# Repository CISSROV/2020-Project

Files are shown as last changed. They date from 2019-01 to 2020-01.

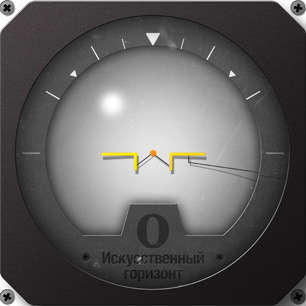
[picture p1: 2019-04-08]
code/web/artificial_horizon/images/tool_320_2.png

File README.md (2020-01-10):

# 2020-Project
CISS ROV-MATE 2020 <br>

### Link to Raspi SD card images
(<a href="https://www.dropbox.com/s/ywiuz3bnbsoy6am/MATE_Topside_2019.img?dl=0">topside</a>, <a href="https://www.dropbox.com/s/pmv8e9o7058bai0/MATE_Camera_2019.img?dl=0">camera</a>, <a href="https://www.dropbox.com/s/j6l58o7ey1v0xhj/MATE_Motor_2019.img?dl=0">motor</a>) (outdated)

### 2019 Presentation link

Documentation: https://drive.google.com/drive/folders/1_E8WjAePvzNWnD8-W-GRQ3ELVlIdNNk-?usp=sharing

### Coding Problems & Code Documentation

Documentation: https://cissrov.github.io/2020-Project/code/

For questions about the code used in 2019 and moved to this repository,  
contact Jonathan Rotter (hydrogen602) at jonathan.p.rotter@gmail.com

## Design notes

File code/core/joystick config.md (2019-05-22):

# NOTES - pygame events and values

### JOYAXISMOTION
event.axis              event.value  
0 - x axis left thumb   (+1 is right, -1 is left)
1 - y axis left thumb   (+1 is down, -1 is up)
2 - left trigger
3 - x axis right thumb  (+1 is right, -1 is left)
4 - y axis right thumb  (+1 is down, -1 is up)
5 - right trigger

### JOYBUTTONDOWN | JOYBUTTONUP
event.button  

A = 0
B = 1
X = 2
Y = 3
LB = 4
RB = 5

BACK = 6
START = 7
XBOX = 8
LEFTTHUMB = 9
RIGHTTHUMB = 10

### idk

[0] - horizontal
[1] - vertival
[0].0 - middle
[0].-1 - left
[0].+1 - right
[1].0 - middle
[1].-1 - bottom
[1].+1 - top

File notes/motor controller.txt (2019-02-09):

Notes for the small motor controllers

Basic code to make them run:

int IN1 = 9; // <- labeled on the controller
int IN2 = 10; // <- labeled on the controller

void setup() {
  pinMode(IN1, OUTPUT);
  pinMode(IN2, OUTPUT);

  digitalWrite(IN1, HIGH); // <- controls the direction of rotation
}

void loop() {
  analogWrite(IN2, 205);
  /* 
   * 2nd argument should be between 0-255
   * It controls speed
   * If IN1 is HIGH, then 255 is stop and 0 is max speed
   * If IN1 is LOW, then 0 is stop and 255 is max speed
   * 
   */
}

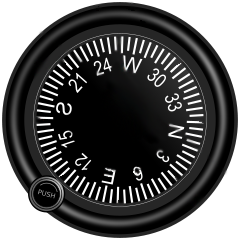
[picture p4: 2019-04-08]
code/web/heading/noplane.png

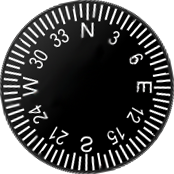
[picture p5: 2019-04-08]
code/web/heading/noplane_center.png

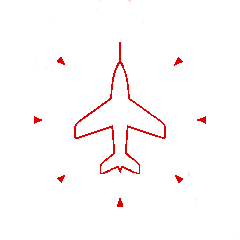
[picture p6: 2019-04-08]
code/web/heading/plane3.png

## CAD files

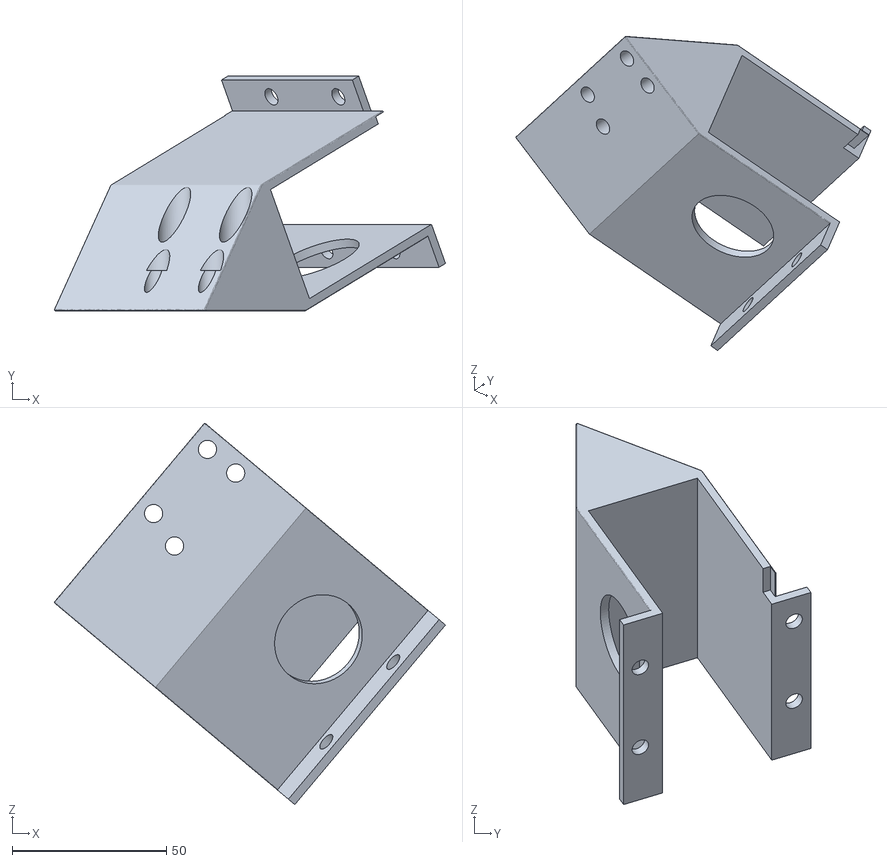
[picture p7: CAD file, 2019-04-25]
STLs/Camera Mount Top downview v2.stl
126.8 x 76.1 x 123.6

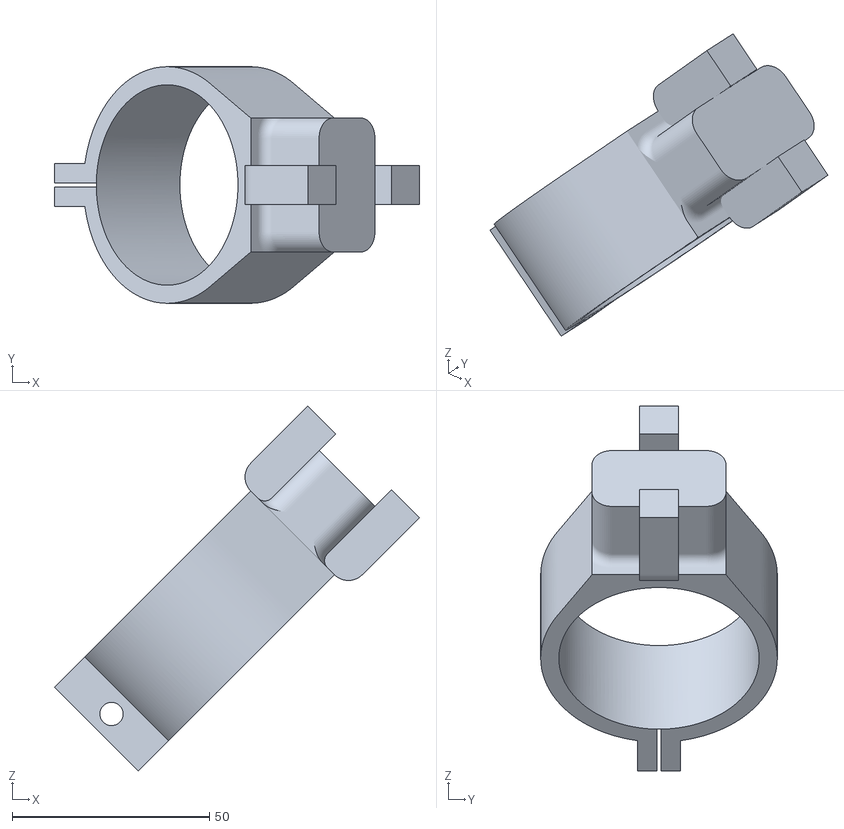
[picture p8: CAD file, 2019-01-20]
STLs/EngineMountClamp/EngineMountClampV0.1.stl
92.6 x 60.0 x 92.6

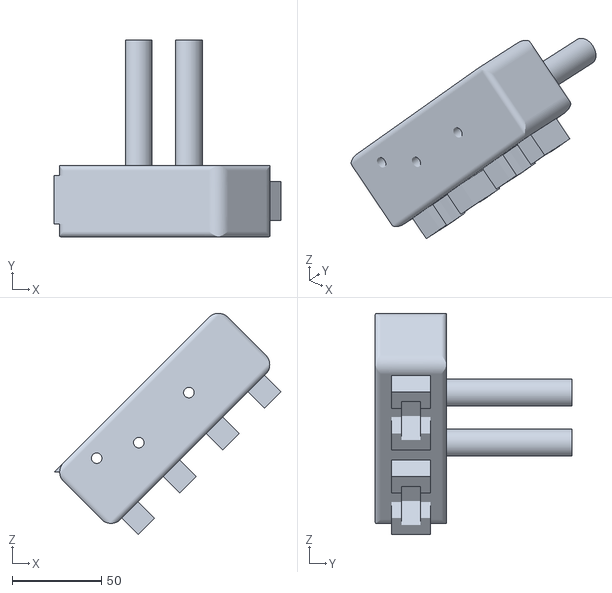
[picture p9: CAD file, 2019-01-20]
STLs/EngineMountHolder/EngineMountHolderV0.1.stl
127.0 x 110.0 x 123.8

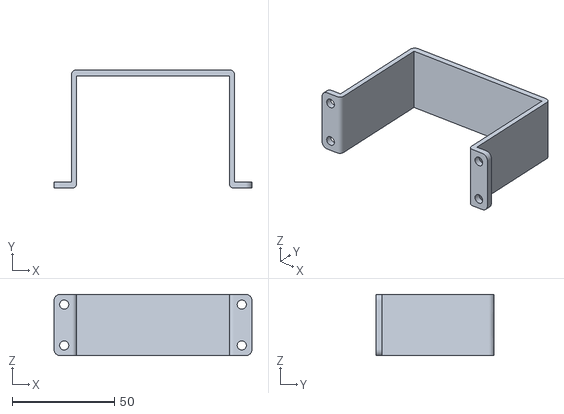
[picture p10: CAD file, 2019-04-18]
STLs/cameramounttop.stl
97.0 x 58.0 x 30.0

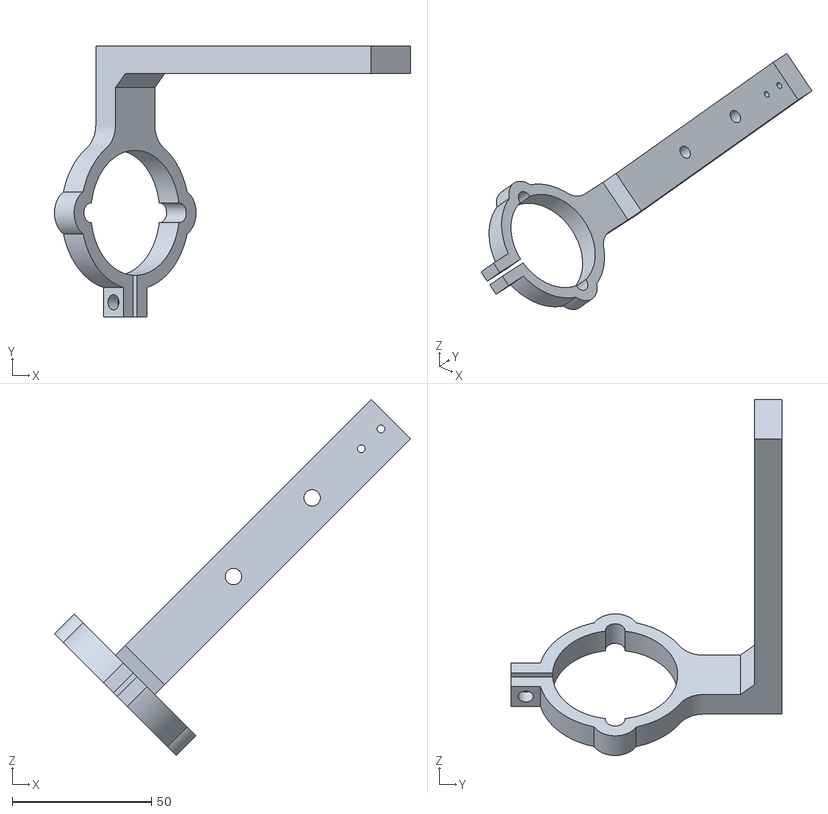
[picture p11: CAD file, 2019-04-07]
STLs/Clamp Base + Mount V2.stl
128.0 x 97.5 x 128.0

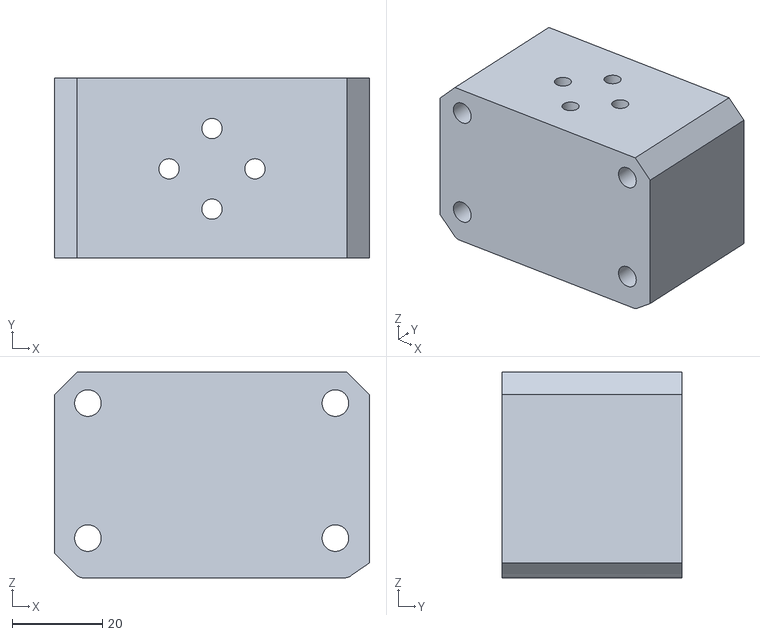
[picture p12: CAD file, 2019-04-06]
STLs/Vert Thruster V3.stl
70.0 x 40.0 x 45.7

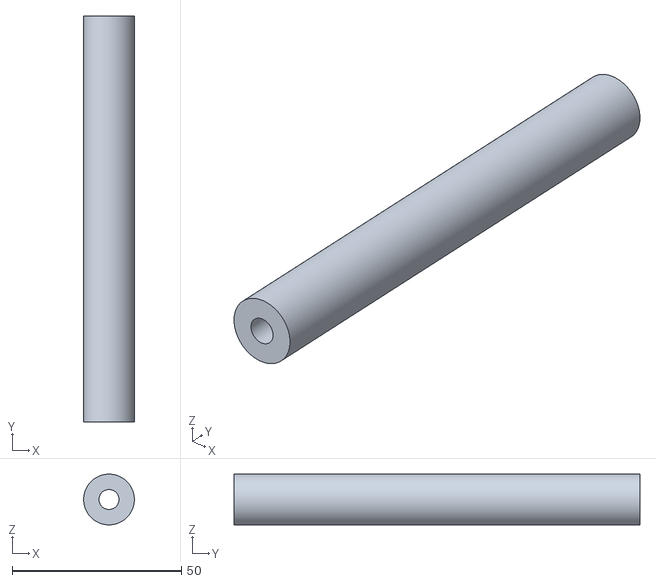
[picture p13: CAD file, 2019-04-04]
STLs/Standoff.stl
15.0 x 120.0 x 15.0

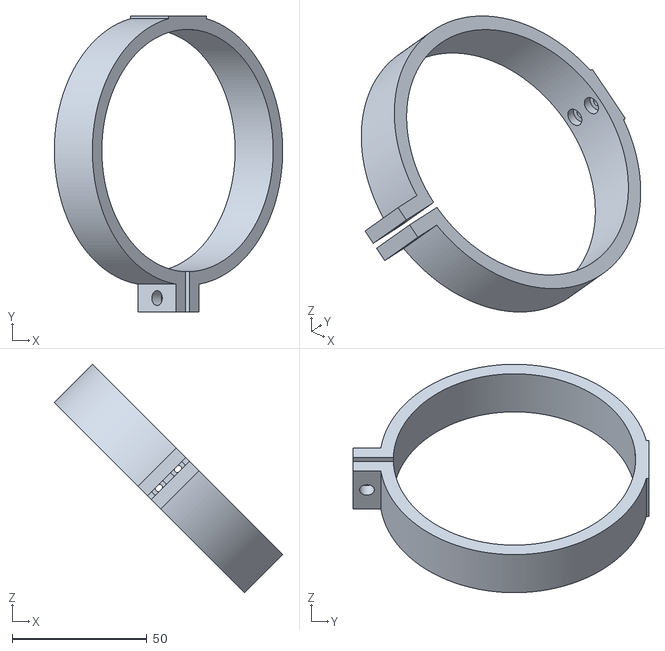
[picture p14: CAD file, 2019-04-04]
STLs/Big Clamp.stl
84.8 x 110.0 x 84.8

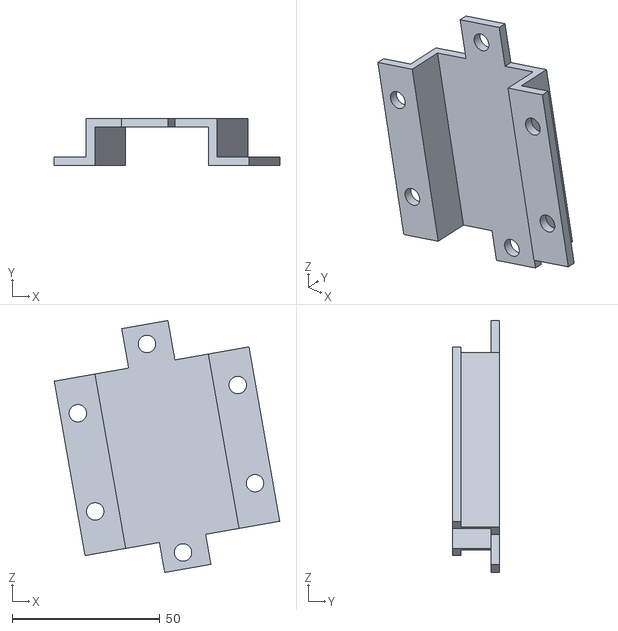
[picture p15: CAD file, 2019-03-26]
STLs/Camera Mount Below Top Piece v2.stl
76.4 x 16.0 x 85.4

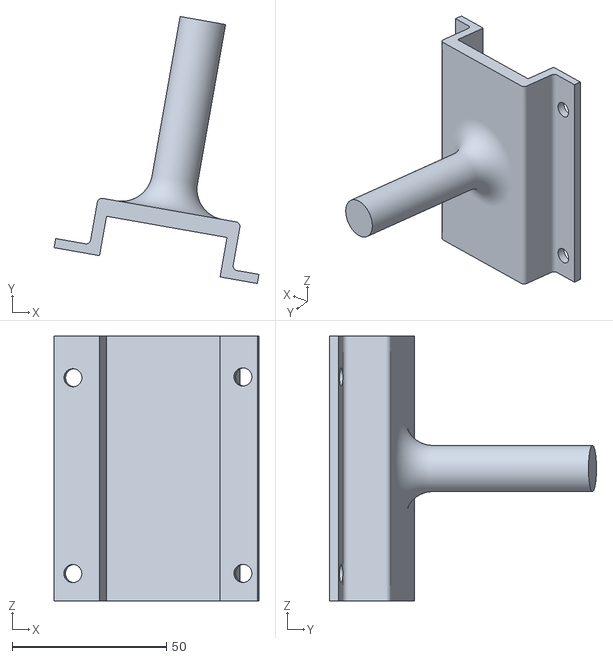
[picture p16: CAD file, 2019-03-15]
STLs/Camera Mount Top Forward_Top Piece v3.stl
66.5 x 86.7 x 86.0

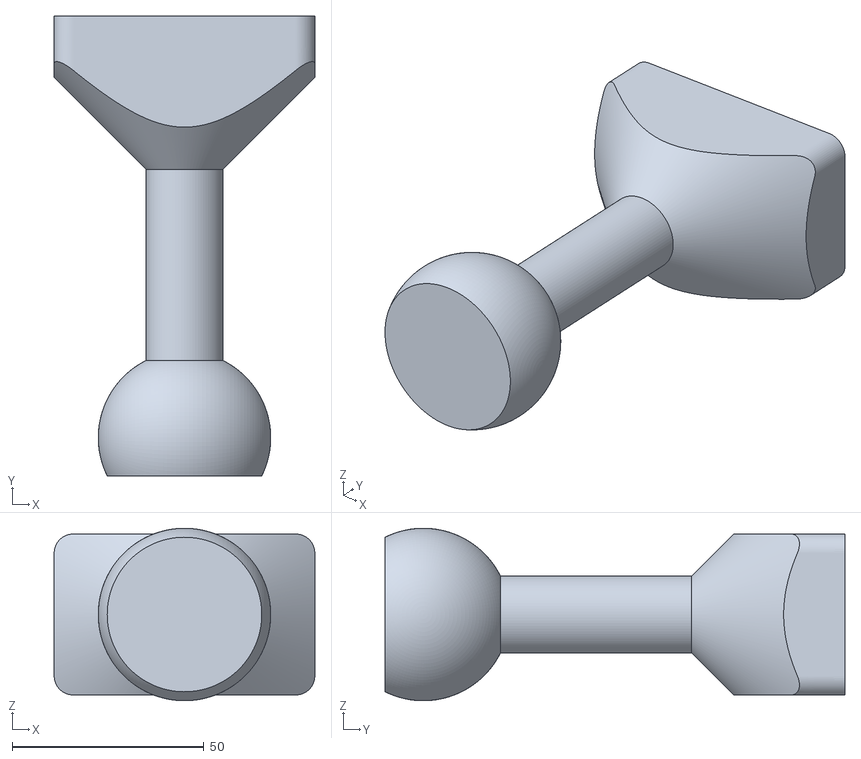
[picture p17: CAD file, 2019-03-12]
STLs/Skinny Stilt.stl
68.0 x 120.0 x 45.0

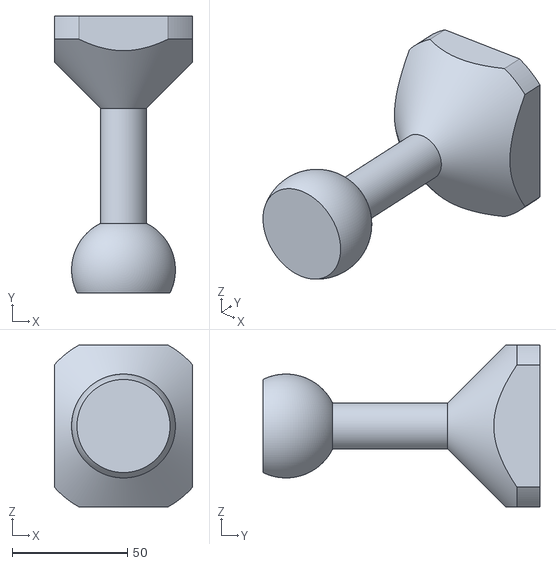
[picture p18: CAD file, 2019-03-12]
STLs/Fat Stilt.stl
60.0 x 120.0 x 70.0

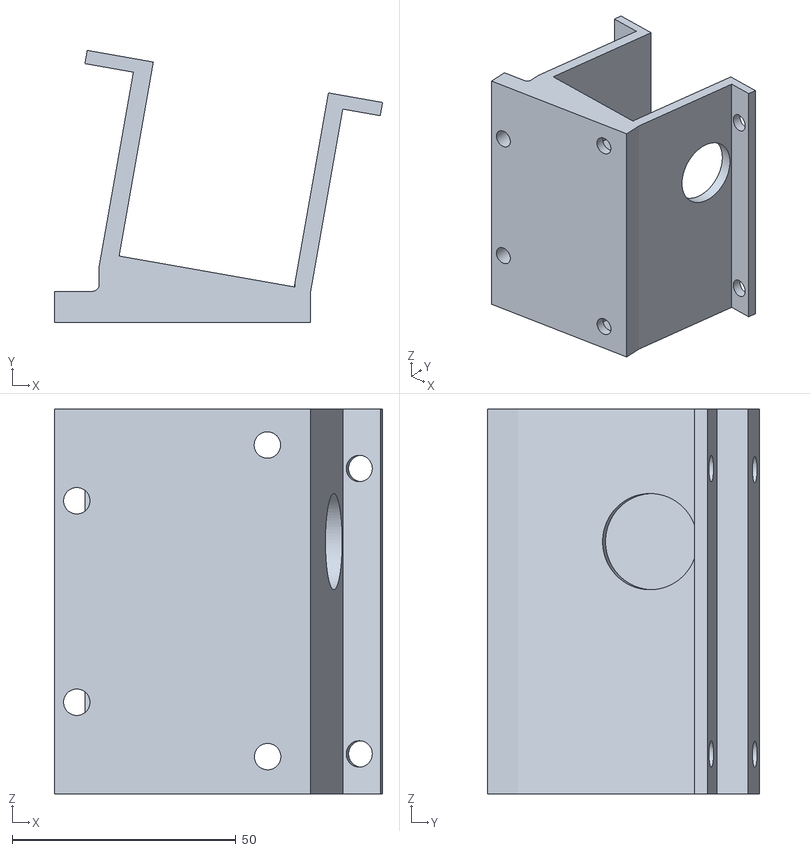
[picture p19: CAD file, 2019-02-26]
STLs/Camera Mount Top Frame Bottom Piece v3.stl
73.3 x 60.8 x 86.0

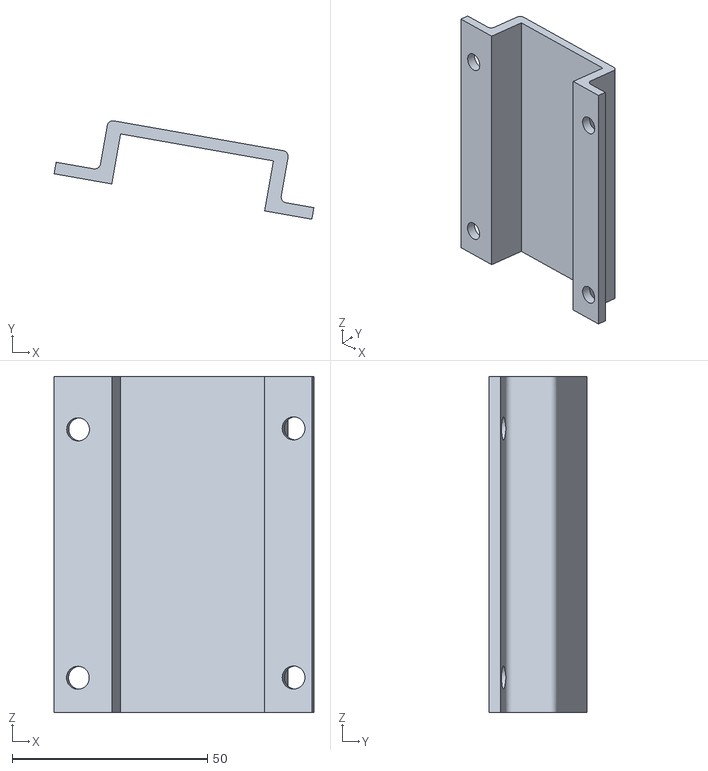
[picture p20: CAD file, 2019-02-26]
STLs/Camera Mount Top Frame Top Piece v2.stl
66.5 x 25.2 x 86.0

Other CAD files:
STLs/Vert Bracket Thruster V2.stl
STLs/Engine Mount Holder rev2_Left Hole.stl
STLs/Camera Mount Below Bottom Piece.stl
STLs/Engine Mount Holder Rev2.stl
STLs/Camera Mount Below Top Piece.stl
STLs/Camera Mount Top Forward_Bottom Piece.stl
STLs/Camera Mount Top Forward_Top Piece.stl
STLs/Camera Mount Top downview.stl
STLs/Tube Mount v2.stl

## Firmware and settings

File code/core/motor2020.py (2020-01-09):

#!/usr/bin/env python3.4
'''Author: Jonathan Rotter

look at motor2020++.py for comments

motor2020++.py features throttling of the vertical thrusters
as the ensuing power surges have cause brown-outs during
the 2019 competition, requiring a full restart of the ROV

This is the old code that does not feature this throttling
And cause I'm lazy and the two files are almost the same,
look at the other one for comments

Required 3rd-party libraries:
`autobahn`
`twisted`
`pyfirmata`
'''

from sys import version
if version[0] != '3':
    raise Exception('This is Python3 code')

import webSocketClient
import json


axis = ['xLeft', 'yLeft', 'triggerLeft', 'xRight', 'yRight', 'triggerRight']
'''List of axis controls on the XBox controllers'''

buttons = ['A', 'B', 'X', 'Y', 'LB', 'RB']
'''List of buttons on the XBox controllers'''

PORT = '/dev/ttyACM0'
'''Location where the Arduino Mega can be found for pyfirmata'''

trimUp = {
    'left': 0.0,
    'right': 0.0
}
'''Stores the default power level of the vertical thrusters.
As the ROV does not have perfect density,
this value can be adjusted by the bumpers (LB, RB) on the controller
to keep the ROV at constant depth when at rest'''

justPressed = [
    {
        'A': False,
        'B': False,
        'X': False,
        'Y': False,
        'LB': False,
        'RB': False
    },
    {
        'A': False,
        'B': False,
        'X': False,
        'Y': False,
        'LB': False,
        'RB': False
    }
]
'''
Stores which buttons are currently pressed
so that code activates only once per
button press and does not repeat
'''

emergencyPower = False
'''Controls whether or not the vertical thrusters
are restrained in their power usage as the
low quality motor controllers make them cause
a voltage drop that can and has caused a brown-out
in the raspberry pis'''

if __name__ == '__main__':
    import pyfirmata

    # setup pyFirmata
    BOARD = pyfirmata.Arduino(PORT)

    # setup an iterator for safety
    iter8 = pyfirmata.util.Iterator(BOARD)
    iter8.start()

    # locate pins
    pins = [
        None,  # no pin 0
        None,  # no pin 1
        BOARD.get_pin('d:2:s'),  # motor 2
        BOARD.get_pin('d:3:s'),  # motor 3
        BOARD.get_pin('d:4:s'),  # motor 4
        BOARD.get_pin('d:5:s'),  # motor 5
        BOARD.get_pin('d:6:s'),  # motor 6 - vertical thruster
        BOARD.get_pin('d:7:s'),  # motor 7 - vertical thruster
        BOARD.get_pin('d:8:s'),  # motor 8 - claw
        BOARD.get_pin('d:9:s'),  # motor 9
        BOARD.get_pin('d:10:s'),  # motor 10
        None,  # no pin 11
        BOARD.get_pin('d:12:s'),  # motor 12
    ]
    '''All pins are put into a list
    so that they can conveniently be referred to
    via pins[pin num]
    example: pins[8].write(150)
    '''


def buttonPressed(button, num):
    '''Specifies what to do if a button is pressed

    Args:
        button (str): The button name: ['A', 'B', 'X', 'Y', 'LB', 'RB']
        num (int): The joystick number, should be either 0 or 1
    '''

    global trimUp, emergencyPower
    # num is zero or one
    if num == 0:
        if button == 'LB':
            trimUp['left'] += 1
            trimUp['right'] += 1
        elif button == 'RB':
            trimUp['left'] -= 1
            trimUp['right'] -= 1
        elif button == 'X':
            emergencyPower = True
        elif button == 'Y':
            emergencyPower = False


def process(data):
    '''Uses a json file of the state of the XBox controller
    to set the motors. The json passed in as `data` must have
    all the labels found in axis and buttons, twice, once
    for each controller. The first twelve are controller 1,
    the second twelve are controller 2

    Args:
        data (str): A json string representing a dict of the controller's state
    '''

    joysticks = json.loads(data)
    assert len(joysticks) == 24  # verify correct count

    joystick1 = dict(zip(axis + buttons, joysticks[:12]))
    joystick2 = dict(zip(axis + buttons, joysticks[12:]))

    old = []  # for debugging

    del data

    global justPressed

    stickNum = 0
    for stick, jPressed in zip((joystick1, joystick2), justPressed):
        for k in stick:
            if k not in buttons:
                continue

            v = stick[k]
            if v == 1 and not jPressed[k]:
                # just pressed
                buttonPressed(k, stickNum)
                jPressed[k] = True
            elif v == 0 and jPressed[k]:
                # just released
                jPressed[k] = False
            elif v not in [1, 0]:
                raise ValueError('Got {0}, expected 0 or 1'.format(v))
            else:
                pass

        stickNum += 1

    del stickNum

    motor_claw = 90

    # print(joystick1)
    if joystick1['A'] and joystick1['B']:
        pass  # do nothing cause both are pressed
    elif joystick1['A']:
        motor_claw = 150
    elif joystick1['B']:
        motor_claw = 30

    # motor setup
    #       150    150
    #       /a/    \b\
    #  4  /////    \\\\\  2
    #
    #               150
    #  5  \\\\\    /////  3
    #      \d\     /c/
    #      150
    # ______________a_b_c_d
    # Back          - - + +
    # Front         + + - -
    # Strafe Left   - + - +
    # Strafe Right  + - + -
    # Rotate Left   - + + -
    # Rotate Right  + - - +
    #

    yLeft = 60 * joystick1['yLeft']
    xLeft = 60 * joystick1['xLeft']  # should be strafe

    global emergencyPower
    if emergencyPower:
        yRight = 60 * joystick1['yRight']
    else:
        yRight = 30 * joystick1['yRight']
        # reduce power to avoid brown outs

    spin = 0

    joystick1['triggerRight'] = (joystick1['triggerRight'] + 1) / 2
    joystick1['triggerLeft'] = (joystick1['triggerLeft'] + 1) / 2

    joystick2['triggerRight'] = (joystick2['triggerRight'] + 1) / 2
    joystick2['triggerLeft'] = (joystick2['triggerLeft'] + 1) / 2

    if joystick1['triggerRight'] >= 0.1 and joystick1['triggerLeft'] >= 0.1:
        pass  # do nothing cause both are pressed
    else:
        if joystick1['triggerRight'] > 0.1:
            # spin right
            spin = joystick1['triggerRight'] * 60

        if joystick1['triggerLeft'] > 0.1:
            # spin left
            spin = -joystick1['triggerLeft'] * 60

    motor_a = 90 + yLeft - xLeft - spin

    motor_b = 90 + yLeft + xLeft + spin

    motor_c = 90 - yLeft + xLeft - spin

    motor_d = 90 - yLeft - xLeft + spin

    # mixing
    # m1 = 90+forwardval+strafeval+turnval
    # m2 = 90+forwardval-strafeval-turnval
    # m3 = 90-forwardval+strafeval
    # m4 = 90-forwardval-strafeval

    global trimUp

    # motors are not running at 93 instead of 90
    # why? I wish I knew
    motor_up_left = 93 - (trimUp['left'] + yRight)
    motor_up_right = 93 - (trimUp['right'] + yRight)  # thrusters reversed

    def bounds(x):
        '''
        Ensures that 30 <= x <= 150 for the motors
        The motors don't respond to higher or lower values
        Rounds result to three decimal points

        Args:
            x (int): Number to ensure is within 30 to 150

        Returns:
            x: An int that fits 30 <= x <= 150
        '''
        if x < 30:
            return 30
        if x > 150:
            return 150
        return round(x, 3)

    def specialBounds(x):
        '''
        Ensures that 20 <= x <= 210 for the vertical thrusters
        Rounds result to three decimal points

        Args:
            x (int): Number to ensure is within 20 to 210

        Returns:
            x: An int that fits 20 <= x <= 210
        '''
        if x < 20:
            return 20
        if x > 210:
            return 210
        return round(x, 3)

    motor_a = bounds(motor_a)
    motor_b = bounds(motor_b)
    motor_c = bounds(180 - motor_c)  # reverse # de reverse
    motor_d = bounds(motor_d)

    motor_up_left = specialBounds(motor_up_left)
    motor_up_right = specialBounds(motor_up_right)

    # right
    pins[4].write(motor_a)
    pins[2].write(motor_b)
    pins[3].write(motor_c)
    pins[5].write(motor_d)

    # 150 down up, 30 move up
    pins[6].write(motor_up_right)  # stop on 93
    pins[7].write(motor_up_left)  # stop on 93

    pins[8].write(motor_claw)

    # print datalist
    for i in range(30):
        # \r is a special character that makes print
        # start at the beginning of the line, overwritting
        # what is already there
        #
        # \033 is the ascii escape character for special
        # terminal instructions
        # \033[A moves the cursor up a line
        # \033[K clears the line
        # refer to http://ascii-table.com/ansi-escape-sequences.php
        #
        # the point of these are to clear the terminal screen
        print('\r\033[A\033[K', end='')

    print('Trim: [{0}, {1}]'.format(trimUp['left'], trimUp['right']))
    print(joystick1)
    print(joystick2)
    print(motor_a, motor_b)
    print(180-motor_c, motor_d)
    print()
    print(motor_up_left, motor_up_right)
    print(motor_claw)
    # global emergencyPower
    if emergencyPower:
        print('-----------------------')
        print('-- MAX POWER ENABLED --')
        print('-----------------------')

    index = 0
    for i in old:
        print(index, i)
        index += 1


if __name__ == '__main__':
    webSocketClient.start('motor', process, ip="192.168.1.2")
    # assumes that motor pi has ip 192.168.1.2

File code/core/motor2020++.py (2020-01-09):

#!/usr/bin/env python3.4
'''Author: Jonathan Rotter

Motor control featuring toggglable throttling of the vertical
thrusters as they have caused brown outs in motor pi

This code is meant to be run on motor pi and requires
a connected arduino mega

The ip of server pi must be specified in the
webSocketClient.start call at the bottom of this file
port is 8008 and is specified in webSocketClient.py

Required 3rd-party libraries:
`autobahn`
`twisted`
`pyfirmata`
'''

# Check if the version of python is 3.x
from sys import version
if version[0] != '3':
    # Stop running if the version is python 2.x
    raise Exception('This is Python3 code')

import webSocketClient
import json

axis = ['xLeft', 'yLeft', 'triggerLeft', 'xRight', 'yRight', 'triggerRight']
buttons = ['A', 'B', 'X', 'Y', 'LB', 'RB']
'''Data labels for axis and buttons in the order
specified by `joystick config.md`
'''

PORT = '/dev/ttyACM0'
'''Port that the arduino mega is connected to'''

# Trim values
trimUp = {
    'left': 0.0,
    'right': 0.0
}
'''Stores the default power level of the vertical thrusters.
As the ROV does not have perfect density,
this value can be adjusted by the bumpers (LB, RB) on the controller
to keep the ROV at constant depth when at rest'''

justPressed = [
    {
        # 1st joystick
        'A': False,
        'B': False,
        'X': False,
        'Y': False,
        'LB': False,
        'RB': False
    },
    {
        # 2nd Joystick
        'A': False,
        'B': False,
        'X': False,
        'Y': False,
        'LB': False,
        'RB': False
    }
]
'''Stores if a button was just pressed to ensure buttons are only processed
once per press.
Changed to true once pressed and false once released'''

emergencyPower = False
'''Specifies if the vertical thrusters are throttled to
prevent power surges causing voltage drops or not'''

currentPower = {
    'left': 93.0,
    'right': 93.0
}
'''Current power level sent to the vertical thrusters'''

if __name__ == '__main__':
    import pyfirmata

    # Setup pyFirmata
    BOARD = pyfirmata.Arduino(PORT)

    # Setup an iterator for safety (no idea what that means, ask Danny or Yilou)
    iter8 = pyfirmata.util.Iterator(BOARD)
    iter8.start()

    # Setup pins
    pins = [
        None,  # no pin 0
        None,  # no pin 1
        BOARD.get_pin('d:2:s'),  # motor 2
        BOARD.get_pin('d:3:s'),  # motor 3
        BOARD.get_pin('d:4:s'),  # motor 4
        BOARD.get_pin('d:5:s'),  # motor 5
        BOARD.get_pin('d:6:s'),  # motor 6 - vertical thruster
        BOARD.get_pin('d:7:s'),  # motor 7 - vertical thruster
        BOARD.get_pin('d:8:s'),  # motor 8 - claw
        BOARD.get_pin('d:9:s'),  # motor 9
        BOARD.get_pin('d:10:s'),  # motor 10
        None,  # no pin 11
        BOARD.get_pin('d:12:s'),  # motor 12
    ]
    '''All pins are put into a list
    so that they can conveniently be referred to
    via pins[pin num]
    example: pins[8].write(150)
    '''


def buttonPressed(button, num):
    '''Specifies what to do if a button is pressed

    Args:
        button (str): The button name: ['A', 'B', 'X', 'Y', 'LB', 'RB']
        num (int): The joystick number, should be either 0 or 1
    '''

    # Check if it received a valid button
    if button not in buttons:
        raise KeyError('Unknown button {}'.format(button))

    global trimUp, emergencyPower

    # If it is the 1st joystick
    if num == 0:
        if button == 'LB':
            # Trim up
            trimUp['left'] += 1
            trimUp['right'] += 1

        elif button == 'RB':
            # Trim down
            trimUp['left'] -= 1
            trimUp['right'] -= 1

        elif button == 'X':
            # Disable throttling
            emergencyPower = True

        elif button == 'Y':
            # Enable throttling
            emergencyPower = False


def process(data):
    '''Uses a json file of the state of the XBox controller
    to set the motors. The json passed in as `data` must have
    all the labels found in axis and buttons, twice, once
    for each controller. The first twelve are controller 1,
    the second twelve are controller 2

    Args:
        data (str): A json string representing a dict of the controller's state
    '''

    global emergencyPower, justPressed

    # Load json string into a list
    joysticks = json.loads(data)
    # Verify the number of entries of the list
    assert len(joysticks) == 24

    # Use the labels to make a dictionary
    # with the keys being labels and values being the joystick values
    joystick1 = dict(zip(axis + buttons, joysticks[:12]))
    joystick2 = dict(zip(axis + buttons, joysticks[12:]))

    old = []  # for debugging

    del data

    # stick is a dict representing one of the joysticks
    # jPressed is a dict found in justPressed
    # stickNum is either 0 or 1 and is used as an argument in buttonPressed()
    #
    # This for loop is for processing button presses
    for stick, jPressed, stickNum in zip((joystick1, joystick2), justPressed, range(2)):
        for k in stick:
            if k not in buttons:
                continue  # only processes button presses, not axis

            # value of button, which is 0 or 1
            v = stick[k]
            if v == 1 and not jPressed[k]:
                # button was just pressed
                buttonPressed(k, stickNum)
                jPressed[k] = True

            elif v == 0 and jPressed[k]:
                # button was just released
                jPressed[k] = False

            elif v not in [1, 0]:
                # Got a value other than 0 or 1 for the state of a button
                raise ValueError('Got {0}, expected 0 or 1'.format(v))

            else:
                pass  # nothing to do

    motor_claw = 90

    # 'A' and 'B' open and close the claw
    if joystick1['A'] and joystick1['B']:
        pass  # do nothing because both are pressed

    elif joystick1['A']:
        motor_claw = 150  # open or close it

    elif joystick1['B']:
        motor_claw = 30  # open or close it

    #   Motor positioning
    #
    #       150    150
    #       /a/    \b\
    #  4  /////    \\\\\  2
    #
    #               150
    #  5  \\\\\    /////  3
    #      \d\     /c/
    #      150
    # ______________a_b_c_d
    # Back          - - + +
    # Front         + + - -
    # Strafe Left   - + - +
    # Strafe Right  + - + -
    # Rotate Left   - + + -
    # Rotate Right  + - - +
    #

    # the joystick values are from -1 to 1
    # scale them to be from -60 to 60
    yLeft = 60 * joystick1['yLeft']
    xLeft = 60 * joystick1['xLeft']  # should be strafe
    yRight = 60 * joystick1['yRight']

    # Code for rotating the ROV

    spin = 0

    # Change the values to be from 0 to 1 instead of from -1 to 1
    joystick1['triggerRight'] = (joystick1['triggerRight'] + 1) / 2
    joystick1['triggerLeft'] = (joystick1['triggerLeft'] + 1) / 2
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

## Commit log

2019-01-21 Delete Tube Mount v2.stl
    moved it to the STLs folder
    [Tube Mount v2.stl]
2019-01-21 Tube Mount v2
2019-01-23 Camera Mount Top Forward
    [Camera Mount Top Forward_Bottom Piece.stl, Camera Mount Top Forward_Top Piece.stl]
2019-01-23 Engine Mount Holder v3
    This version should have lower clearances in the fitting areas.
    [Engine Mount Holder v3.stl]
2019-01-29 Add files via upload
    Current: arm v9 copy.f3d
    [arm v2.f3d, arm v4.f3d, arm v5.f3d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]
2019-02-09 Create motor controller.txt
2019-02-09 Create motorControlProtocol.txt
    describes how the mini-rov interacts with the base station via tcp
2019-03-12 Fat Stilts
    [Fat Stilts.stl]
2019-03-12 Skinny Stilt
    [Skinny Stilt.stl]
2019-03-12 Fat Stilt
    [Fat Stilt.stl]
2019-03-15 Camera Mount Top Forward_Top Piece v2
    [Camera Mount Top Forward_Top Piece v2.stl]
2019-03-26 Camera Mount Below Top Piece v2
    [Camera Mount Below Top Piece v2.stl]
2019-03-26 Camera Mount Top Forward_Top Piece v3
    [Camera Mount Top Forward_Top Piece v3.stl]
2019-04-04 Thruster Mounts V2
    Created after a request from Joshua to relocate thruster mounts below the robot rather than off the sides. The vertical thruster brackets have been modified to be attached onto the bottom frame at four points rather than being attached at two points, because it can no longer be joined to the thruster mounts.
    [Big Clamp.stl, Clamp Base + Mount.stl, Standoff.stl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]
2019-04-07 Deleting for revised version
    [Clamp Base + Mount.stl]
2019-04-07 Adding revised version of piece
    [Clamp Base + Mount V2.stl]
2019-04-09 full adoption of web sockets
2019-04-15 Camera Mount Below Bottom Piece v2
    [Camera Mount Below Bottom Piece v2.stl]
2019-04-16 Camera Mount Top downview
    [Camera Mount Top downview.stl]
2019-04-16 i want to die
2019-04-18 from joshua
    [cameramounttop.stl]
2019-04-20 claw code
2019-04-20 added option for adding and removing temp sensor
2019-04-20 im tired
2019-04-20 im too tired
2019-04-25 Camera Mount Top downview v2
    [Camera Mount Top downview v2.stl]
2019-04-25 vertical thrusters reversed
2019-04-26 fixes cause im retarded
    [hydrogenMiniROVClient2020.py, webSocketClient.py]
2019-04-27 switching stuff
2019-04-30 clean up
    [arm v2.f3d, arm v4.f3d, arm v5.f3d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]
2019-05-22 documentation for motor2020
2020-01-10 docs for sensors and combined all into one module
